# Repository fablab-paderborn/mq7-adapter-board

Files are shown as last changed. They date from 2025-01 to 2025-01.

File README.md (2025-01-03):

MQ7 Adapter Board
=================

This board implement the circuit proposed by home assistant to enable the
proper cycling of the sensor: https://devices.esphome.io/devices/MQ-7

It provides a cleaner and easier to accomplish (in some regards) solution
compared to modifying the original breakout board. You can also source
the parts without the original board.

This board does not include a power led that is lit when 5V is present
as I did not find that particular useful. 

Notes
=====

There are a few design choices for the board. Some of them them, e.g. 
the selection of R1 also apply if you do the modification on the
original breakout board.

Selection of R1
---------------
The MQ7 and MQ7B require different resistors for R1. The 75Ω used in the 
circuit here will result in 1.5V voltage across the heating element in the 
MQ7 when HEAT input is low, which is the required value for the MQ7B. If 
you are using a MQ7, the voltage should be 1.4V. This requires R1 to be 82Ω
or 86Ω assuming 33Ω for the heater itself.

It should also be possible to leave R1 unpopulated and use PWM with a duty
cycle that is equivalent to 1.4V/1.5V instead and save the 160mW that this
resistor burns but I have not tested that.

Selection of R5
---------------
When going with the original schematics, R5 is 0Ω and just be bridged
by solder.  If you want to play a bit safer and protect the IO pin of
ESP, it is recommended to use something like 100Ω here.

Order of pins
------------
Please note that VCC and GND are reversed in comparison to the common MQ7
breakout board that constantly heats the sensor.

Holes for the MQ7 sensor
------------------------
The holes for the MQ7 are 1mm. This is enough for new sensors. If you 
desoldered an MQ7 sensor, you might need to enlarge the holes a bit to
fit a desoldered sensors or adjust the hole sizes in the project.

Finished board
==============
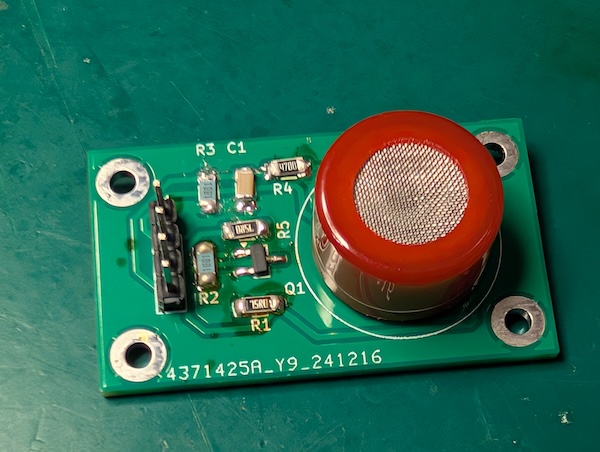
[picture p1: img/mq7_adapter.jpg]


Schematics
==========
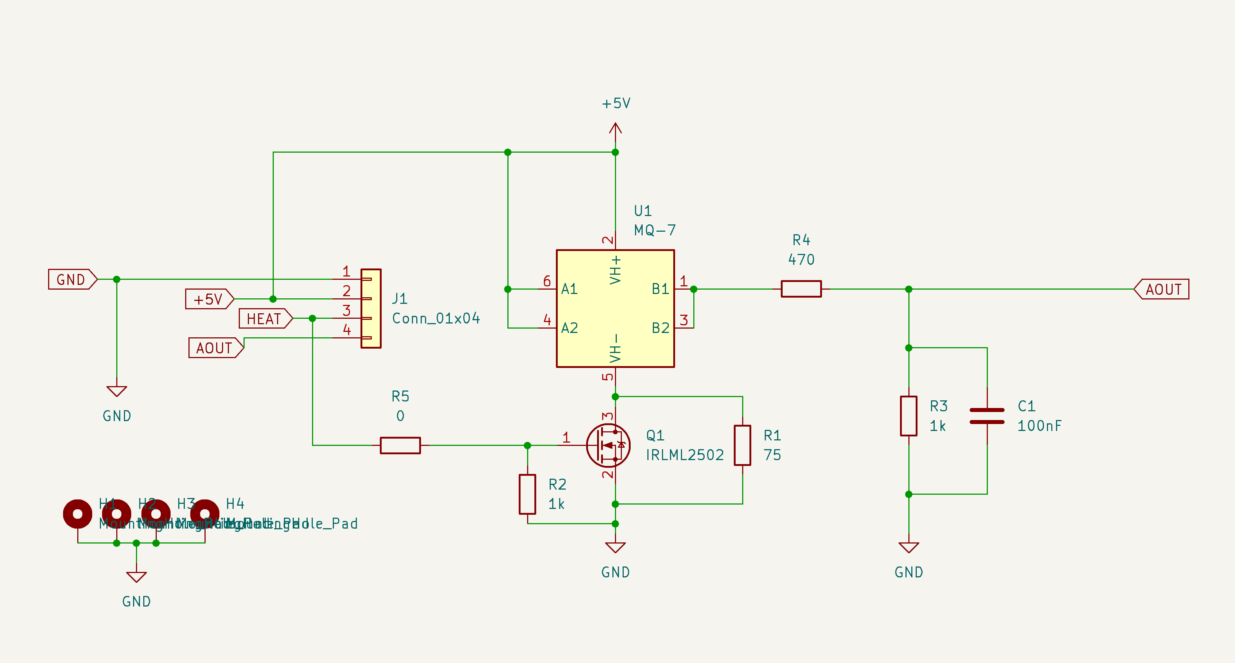
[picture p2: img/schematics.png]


Bill of materials
=================

| Qty | Reference | Value | Notes |
|----:|---|---|---|
| 1 | C1 | 100nF | |
| 1 | J1 | Conn 1x4  | |
| 1 | Q1 | IRLML2502 | Or other SOT23 N-channel mosfet, e.g. SL2310 |
| 1 | R1 | 75 | or 82Ω/86Ω. See Note on selection of R1 |
| 2 | R2,R3 | 1k | |
| 1 | R4 | 470 | |
| 1 | R5 | 100 | Or 0Ω See note on R5 | 
| 1 | U1 | MQ-7 | |

The IRLML2502 transistor is the one that I had on hand and used. The original
modification recommends the SL2310. But any N-Channel mosfet with V_GS < 3.3V
that can handle the ~150 mA should work fine.

License
=======
This project is licensed under the 
[CC BY-SA 4.0](https://creativecommons.org/licenses/by-sa/4.0/) license

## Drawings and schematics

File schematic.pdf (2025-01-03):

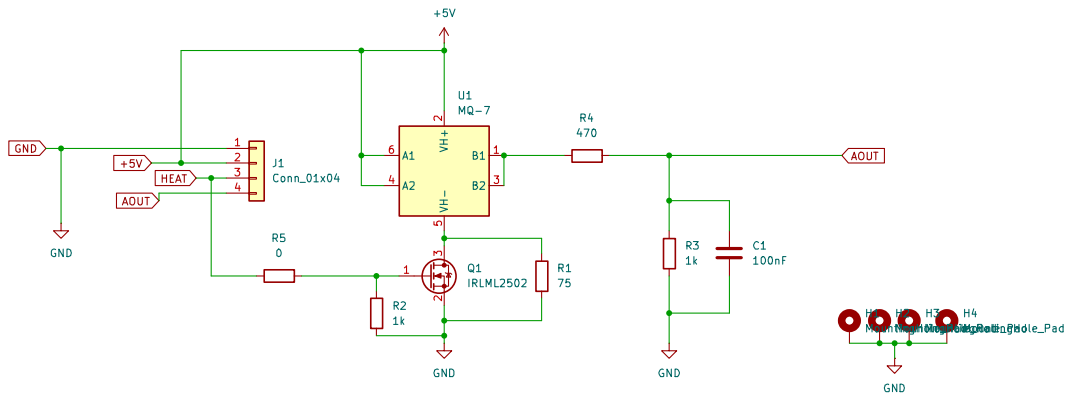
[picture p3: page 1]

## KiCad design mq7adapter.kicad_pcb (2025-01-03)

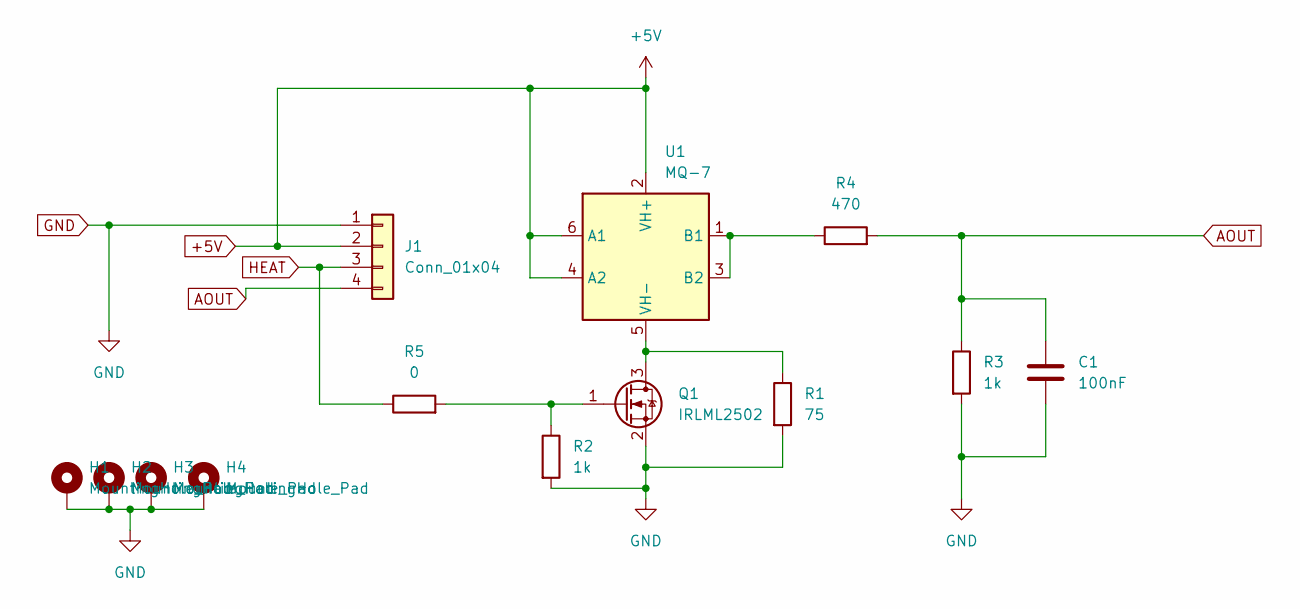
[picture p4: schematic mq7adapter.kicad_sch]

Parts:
C1: 100nF; C_1206_3216Metric_Pad1.33x1.80mm_HandSolder
H1, H2, H3, H4: MountingHole_Pad; MountingHole_2.5mm_Pad
J1: Conn_01x04; PinHeader_1x04_P2.54mm_Vertical
Q1: IRLML2502; SOT-23_Handsoldering
R1: 75; R_1206_3216Metric_Pad1.30x1.75mm_HandSolder
R2, R3: 1k; R_1206_3216Metric_Pad1.30x1.75mm_HandSolder
R4: 470; R_1206_3216Metric_Pad1.30x1.75mm_HandSolder
R5: 0; R_1206_3216Metric_Pad1.30x1.75mm_HandSolder
U1: MQ-7; MQ-6

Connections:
+5V: J1.2, U1.2 (VH+), U1.4 (A2), U1.6 (A1)
AOUT: C1.1, J1.4, R3.1, R4.2
GND: C1.2, H1.1, H2.1, H3.1, H4.1, J1.1, Q1.2 (S), R1.2, R2.2, R3.2
HEAT: J1.3, R5.1
unnamed: Q1.3 (D), R1.1, U1.5 (VH-)
unnamed: Q1.1 (G), R2.1, R5.2
unnamed: R4.1, U1.1 (B1), U1.3 (B2)

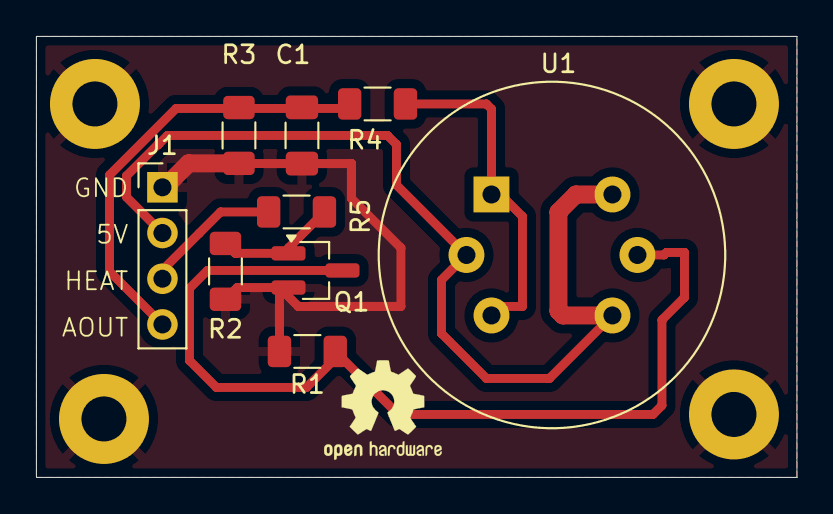
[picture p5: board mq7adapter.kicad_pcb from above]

Board: 2 copper layers, 42.2 x 24.5 mm, 13 parts (0 on the bottom side), 7 nets.

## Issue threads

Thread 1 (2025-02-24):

Add LED for when heating...

puterboy, 2025-02-24:
The HA page on the MQ-7 mod flips the polarity of the existing LED so that it goes on when the sensor is heating. This seems more interesting and helpful than just indicating power.

You might want to add this an *optional* component on your board.

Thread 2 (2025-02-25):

Questions about the schematic

puterboy, 2025-02-25:
I looked at the datasheet for the MQ-7 sensor (https://cdn.sparkfun.com/datasheets/Sensors/Biometric/MQ-7%20Ver1.3%20-%20Manual.pdf)
Couple of comments and questions.

1. Per the specs, RH = 29 +/- 3 ohms (vs. 32 in your writeup) - this would suggest using 68 ohms to get 1.5v and 75 ohms for 1.4v if you assume the midpoint resistance.
2. The datasheet suggests using a load resistor for the output RL=4.7K whereas the voltage divider you have presents a total load to ground of 1.47K (I am assuming the cap is only there to suppress noise transients and doesn't affect the DC load).
Would it be better to use a voltage divider of say 1.6K and 3K which gives a total load resistance of 4.6K and since VRL peaks at just over 4.5v, this would give a slightly improved dynamic range of 0-3.1v on the analog input.
3. Maybe I am missing something, but I don't understand how changing R5 to 100R would add any meaningful protection to the gpio pin given that it already has 1K to ground so 1.1K to ground won't change much (and the FET has typically megohms of input impedance)
4. The specs call for a supply of 5 +/- 0.1v while typically the 5v USB supply on an esp32 will at best be +/-0.3v and will vary with load.
Would it be better to use a 5v boost converter off the 3.3v pin on the esp32.
5. Finally, did you find that buying the naked MQ-7 is no cheaper than the one with the board?

Please feel free to correct me if any of my assumptions and analyses are wrong.

THanks

schwabe, 2025-02-25:
1.  Probably best to measure the sensor. This other datasheet that I used says 33 Ohm:  https://cdn.sparkfun.com/assets/b/b/b/3/4/MQ-7.pdf
2. Sure. I just used the same resistor values as the modification that this circuit is based on.
3. The resistor is probably not needed. But it is more to protect the output of the inrush current for any capacitance that the fet might have when switching on.
4. I think that heavily depends on the USB power supply that you are using. Using a boost converter of the 3.3v pin will almost certainly kill that small 3.3v regulator as you use 750 mW during the on period of the heating. The usb power supplies that I have here are all good enough in reality to be in the 5V +/- 0.1V. Especially when under the load of the circuit of 250-750 mW.
5. I don't remember prices but the modules that you find with the MQ7 on them have a circuit that is not helpful. But the MQ7 is quite cheap on aliexpress, so I would just buy the one without board to avoid the desoldering.

From the measurements that I have seen on my esphome, I don't think that sensor is that precise anyway and also suffers from sensitivity to other gases. Just clean something with isoproponal in the same room and it is reporting high CO concentration.
